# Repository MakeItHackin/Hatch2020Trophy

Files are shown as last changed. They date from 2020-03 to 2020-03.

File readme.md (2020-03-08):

Thanks for visiting this page to learn more about your HATCH trophy!  

View my YouTube video for a quick overview and demo:  
https://www.youtube.com/watch?v=jdO1fBBoojo

The trophy uses open source code and hardware, so please hack it to make it do what you want.  It comes loaded with some demo code to test each of the components.  

There will be updates to this page in the coming weeks, but if you have any questions or comments, please initiate a "Issue" on github, and I will answer as soon as I can.  

With the demo code loaded, the trophy will boot to the 'award' screen.  
Press buttons 'A' or 'B' to scroll through the menu.  
'A' and 'B' buttons serve as scrolling features through the submenus as well.  
The 'C' button is used as a 'select' button  
The 'D' button is used as a 'select' button during the 'Set Clock' Function  

When you go into the 'Demo Mode' Function, the program will loop forever.  To exit the loop, just press the reset button.  
  
The following functions are loaded with the demo software:  
View Clock (see the date/time/temperature from the DS3231 Real Time Clock module)  
Set Clock (change the clock's time)  
View Temp (see the temperature from the DS3231 Real Time Clock Module)  
Lite Sense (view the analog signal from the light sensor.  Minimum is 0 / dark and Maximum is 1023 / very very bright)  
Neopixels (cycles through a red/green/blue 'color wipe' animation)  
Buzzer (plays the Super Mario theme song)  
LEDs (cycles through LEDs on the DNA strand)  
Battery (view battery voltage)  
Demo Mode (scrolls through all features, sensors, and animations)  
  
The trophies feature the following major components:  
Arduino Nano (clone) microcontroller  
DS3231 Real Time Clock (with temperature Sensor)  
18650 Battery, along with charging circuit and DC-DC boost coverter to power the Arduino  
128x32 Pixel OLED display  
Piezo Buzzer  
Light Sensor  
Neopixel (WS2812v3) RGB LEDs  
Surface mount LEDs  
SAO v1.69 Connector

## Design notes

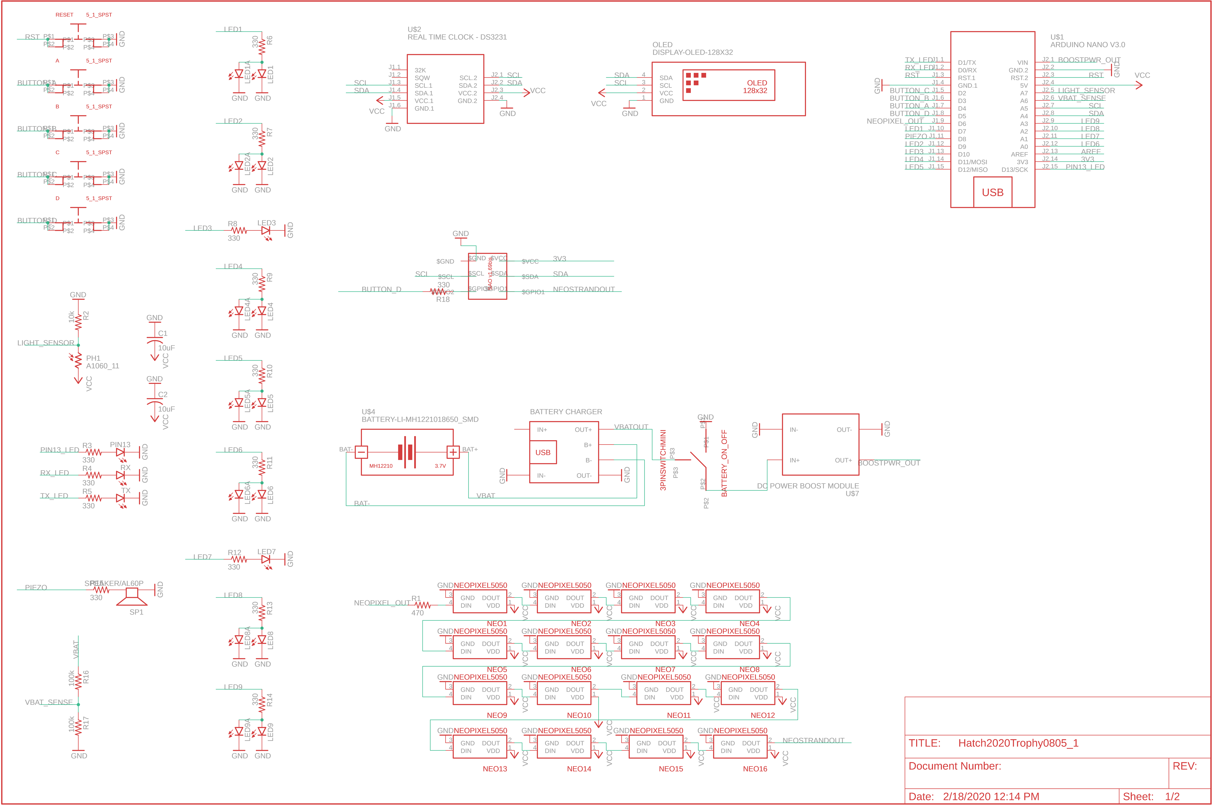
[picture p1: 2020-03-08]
CircuitBoard/TrophySchematic.png

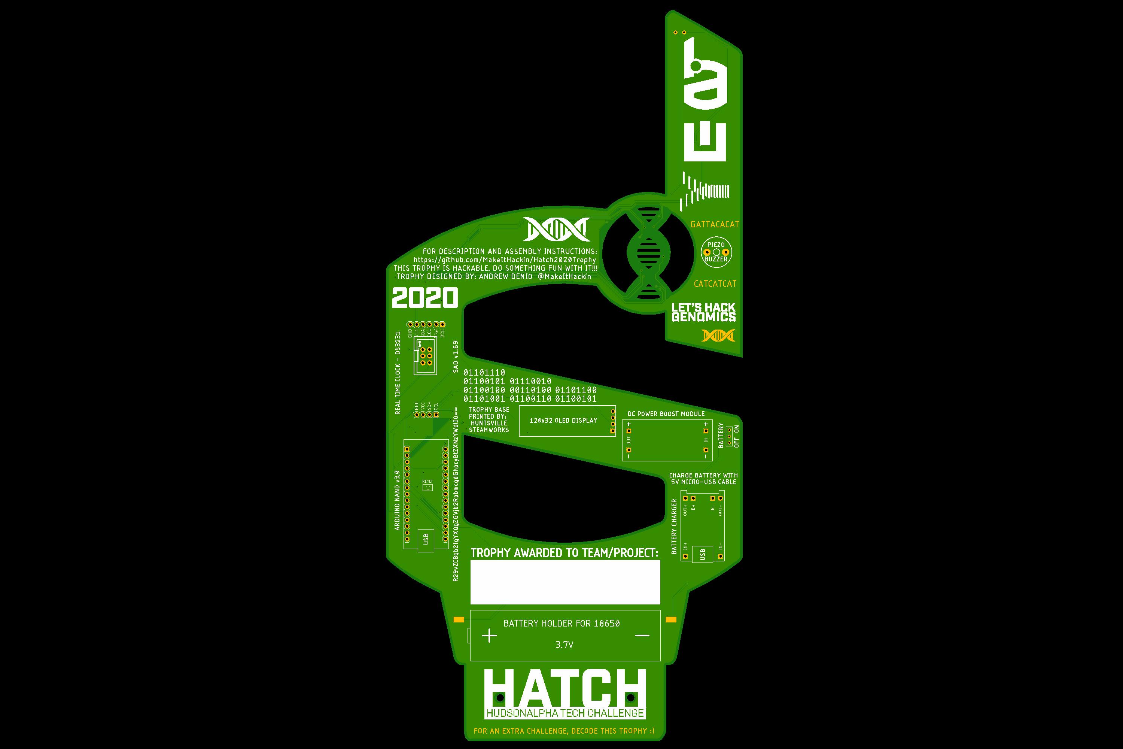
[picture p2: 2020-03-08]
CircuitBoard/TrophyBottom.jpg

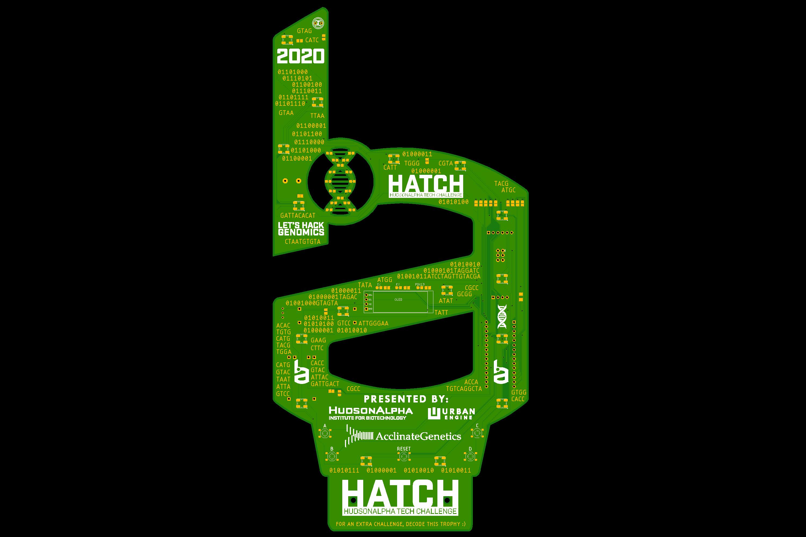
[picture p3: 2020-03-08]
CircuitBoard/TrophyTop.jpg

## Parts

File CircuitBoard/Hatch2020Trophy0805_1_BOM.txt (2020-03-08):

Partlist exported from C:/Users/Andrew/Documents/EAGLE/projects/HATCH 2020 Trophy/Hatch2020Trophy0805_1.sch at 2/18/2020 12:30 PM

Part           Value                       Device                        Package              Description                                                                                                       POPULARITY SPICEPREFIX
A              5_1_SPST                    5_1_SPST                      5_1_SPST                                                                                                                                                     
B              5_1_SPST                    5_1_SPST                      5_1_SPST                                                                                                                                                     
BATTERY_ON_OFF 3PINSWITCHMINI              3PINSWITCHMINI                3PINMINI                                                                                                                                                     
C              5_1_SPST                    5_1_SPST                      5_1_SPST                                                                                                                                                     
C1             10uF                        C-USC0805                     C0805                CAPACITOR, American symbol                                                                                        63         C          
C2             10uF                        C-USC0805                     C0805                CAPACITOR, American symbol                                                                                        63         C          
D              5_1_SPST                    5_1_SPST                      5_1_SPST                                                                                                                                                     
LED1                                       LEDSML0805                    SML0805              LED                                                                                                               17                    
LED1A                                      LEDSML0805                    SML0805              LED                                                                                                               17                    
LED2                                       LEDSML0805                    SML0805              LED                                                                                                               17                    
LED2A                                      LEDSML0805                    SML0805              LED                                                                                                               17                    
LED3                                       LEDSML0805                    SML0805              LED                                                                                                               17                    
LED4                                       LEDSML0805                    SML0805              LED                                                                                                               17                    
LED4A                                      LEDSML0805                    SML0805              LED                                                                                                               17                    
LED5                                       LEDSML0805                    SML0805              LED                                                                                                               17                    
LED5A                                      LEDSML0805                    SML0805              LED                                                                                                               17                    
LED6                                       LEDSML0805                    SML0805              LED                                                                                                               17                    
LED6A                                      LEDSML0805                    SML0805              LED                                                                                                               17                    
LED7                                       LEDSML0805                    SML0805              LED                                                                                                               17                    
LED8                                       LEDSML0805                    SML0805              LED                                                                                                               17                    
LED8A                                      LEDSML0805                    SML0805              LED                                                                                                               17                    
LED9                                       LEDSML0805                    SML0805              LED                                                                                                               17                    
LED9A                                      LEDSML0805                    SML0805              LED                                                                                                               17                    
NEO1           NEOPIXEL5050                NEOPIXEL5050                  NEOPIXEL5050                                                                                                                                                 
NEO2           NEOPIXEL5050                NEOPIXEL5050                  NEOPIXEL5050                                                                                                                                                 
NEO3           NEOPIXEL5050                NEOPIXEL5050                  NEOPIXEL5050                                                                                                                                                 
NEO4           NEOPIXEL5050                NEOPIXEL5050                  NEOPIXEL5050                                                                                                                                                 
NEO5           NEOPIXEL5050                NEOPIXEL5050                  NEOPIXEL5050                                                                                                                                                 
NEO6           NEOPIXEL5050                NEOPIXEL5050                  NEOPIXEL5050                                                                                                                                                 
NEO7           NEOPIXEL5050                NEOPIXEL5050                  NEOPIXEL5050                                                                                                                                                 
NEO8           NEOPIXEL5050                NEOPIXEL5050                  NEOPIXEL5050                                                                                                                                                 
NEO9           NEOPIXEL5050                NEOPIXEL5050                  NEOPIXEL5050                                                                                                                                                 
NEO10          NEOPIXEL5050                NEOPIXEL5050                  NEOPIXEL5050                                                                                                                                                 
NEO11          NEOPIXEL5050                NEOPIXEL5050                  NEOPIXEL5050                                                                                                                                                 
NEO12          NEOPIXEL5050                NEOPIXEL5050                  NEOPIXEL5050                                                                                                                                                 
NEO13          NEOPIXEL5050                NEOPIXEL5050                  NEOPIXEL5050                                                                                                                                                 
NEO14          NEOPIXEL5050                NEOPIXEL5050                  NEOPIXEL5050                                                                                                                                                 
NEO15          NEOPIXEL5050                NEOPIXEL5050                  NEOPIXEL5050                                                                                                                                                 
NEO16          NEOPIXEL5050                NEOPIXEL5050                  NEOPIXEL5050                                                                                                                                                 
OLED           DISPLAY-OLED-128X32         DISPLAY-OLED-128X32           DISPLAY-OLED-128X32  128x32 Dot Matrix OLED Module with I2C interface based on SSD1306 chip                                                                  
PH1            A1060_11                    A1060_11                      T0-46-A10XX          Sensor Robust Light Sensing Applications                                                                          0                     
PIN13                                      LEDSML0805                    SML0805              LED                                                                                                               17                    
R1             470                         R-US_R0805                    R0805                RESISTOR, American symbol                                                                                         85         R          
R2             10k                         R-US_R0805                    R0805                RESISTOR, American symbol                                                                                         85         R          
R3             330                         R-US_R0805                    R0805                RESISTOR, American symbol                                                                                         85         R          
R4             330                         R-US_R0805                    R0805                RESISTOR, American symbol                                                                                         85         R          
R5             330                         R-US_R0805                    R0805                RESISTOR, American symbol                                                                                         85         R          
R6             330                         R-US_R0805                    R0805                RESISTOR, American symbol                                                                                         85         R          
R7             330                         R-US_R0805                    R0805                RESISTOR, American symbol                                                                                         85         R          
R8             330                         R-US_R0805                    R0805                RESISTOR, American symbol                                                                                         85         R          
R9             330                         R-US_R0805                    R0805                RESISTOR, American symbol                                                                                         85         R          
R10            330                         R-US_R0805                    R0805                RESISTOR, American symbol                                                                                         85         R          
R11            330                         R-US_R0805                    R0805                RESISTOR, American symbol                                                                                         85         R          
R12            330                         R-US_R0805                    R0805                RESISTOR, American symbol                                                                                         85         R          
R13            330                         R-US_R0805                    R0805                RESISTOR, American symbol                                                                                         85         R          
R14            330                         R-US_R0805                    R0805                RESISTOR, American symbol                                                                                         85         R          
R15            330                         R-US_R0805                    R0805                RESISTOR, American symbol                                                                                         85         R          
R16            100k                        R-US_R0805                    R0805                RESISTOR, American symbol                                                                                         85         R          
R17            100k                        R-US_R0805                    R0805                RESISTOR, American symbol                                                                                         85         R          
R18            330                         R-US_R1206                    R1206                RESISTOR, American symbol                                                                                         19         R          
RESET          5_1_SPST                    5_1_SPST                      5_1_SPST                                                                                                                                                     
RX                                         LEDSML0805                    SML0805              LED                                                                                                               17                    
SP1            SPEAKER/AL60P               SPEAKER/AL60P                 AL60P                SPEAKER Source: BuerklinAdded PS12 (for part # PS1240 piezo) http://www.ladyada.net/library/pcb/eaglelibrary.html                       
TX                                         LEDSML0805                    SML0805              LED                                                                                                               17                    
U$1            ARDUINO NANO V3.0           ARDUINO-NANO-3.0              ARDUINO-NANO-3.0     Arduino Nano 3.0 and compatible devices                                                                                                 
U$2            REAL TIME CLOCK - DS3231    RTC-DS3231-AT24C32            RTC-DS3231-AT24C32   RTC Module with Battery and EEPROM based on DS3231 and AT24C32 chips                                                                    
U$3            SAO-1.69                    SAO-1.69                      2X3-SHROUDED-FEMALE                                                                                                                                          
U$4            BATTERY-LI-MH1221018650_SMD BATTERY-LI-MH1221018650_SMD   BATTERY_18650_SMD    Lithium-Ion MH12210 Rechargeable Battery                                                                                                
U$6            BATTERY CHARGER             BATTERY-CHARGER-LI-PROTLOW_FP BAT_CHARGE_LOW_FP    Lithium Battery 5V Charger with protection circuit                                                                                      
U$7            DC POWER BOOST MODULE       DC-DC-STEP-UP-MT3608LOW_FP    DC-DC-STEP-UP-LOW_FP DC/DC Step-Up Regulator based on MT3608 chip

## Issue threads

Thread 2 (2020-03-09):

0805 SMD LEDs too bright?

MakeItHackin, 2020-03-09:
The surface mounted LEDs in the DNA strand and above the OLED display might be a little too bright.  Changing out the resistors to a higher resistance may help (but would require resoldering).  I'll consider increasing the resistance if other trophies are ordered

Closed 2020-03-10.

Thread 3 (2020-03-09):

Some trophies will not upload code to Arduino while Arduino is plugged into trophy

MakeItHackin, 2020-03-09:
Some trophies will not upload code to Arduino while Arduino is plugged into trophy.  But upload works fine when arduino is unplugged.  I'm not sure why this is happening.

MakeItHackin, 2020-03-10:
seems to be going into some kind of reset mode.  the com port disappears for a few seconds in Device manager and Windows plays a tone like the device has disconnected.  The device reconnects, but doesn't play the "reconnecting" sound.  The LEDs on arduino also indicate that the board is going through some sort of reset.

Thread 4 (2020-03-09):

Weird Sound seems to be coming from buzzer during LED animations

MakeItHackin, 2020-03-09:
During LED animations (regular and neo pixel), some trophies produce a high pitch, very low volume noise.  I'm not sure where this is coming from or what is causing it.  I will try and troubleshoot and resolve it.

MakeItHackin, 2020-03-10:
Apparently, this has happened with other people and is said to be caused by the power circuit on the oled display.  i might try and add some pullup or pulldown resistors to see if it changes anything.

MakeItHackin, 2020-03-10:
Seems to have reduced slightly in TrophyDemoMode12 build

MakeItHackin, 2020-03-10:
Seems to have reduced slightly in TrophyDemoMode12 build

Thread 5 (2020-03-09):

Reassign the 'C' button functionality for 'select'.  Use 'D' Button instead

MakeItHackin, 2020-03-09:
'C' is assigned to the interrupt pin (2).  Save that button for something else.  Use 'D' instead to beused as select for everything else.  It is currently being used as the select button for setting the clock.

MakeItHackin, 2020-03-10:
Changed with TophyDemoMode12.

Closed 2020-03-10.

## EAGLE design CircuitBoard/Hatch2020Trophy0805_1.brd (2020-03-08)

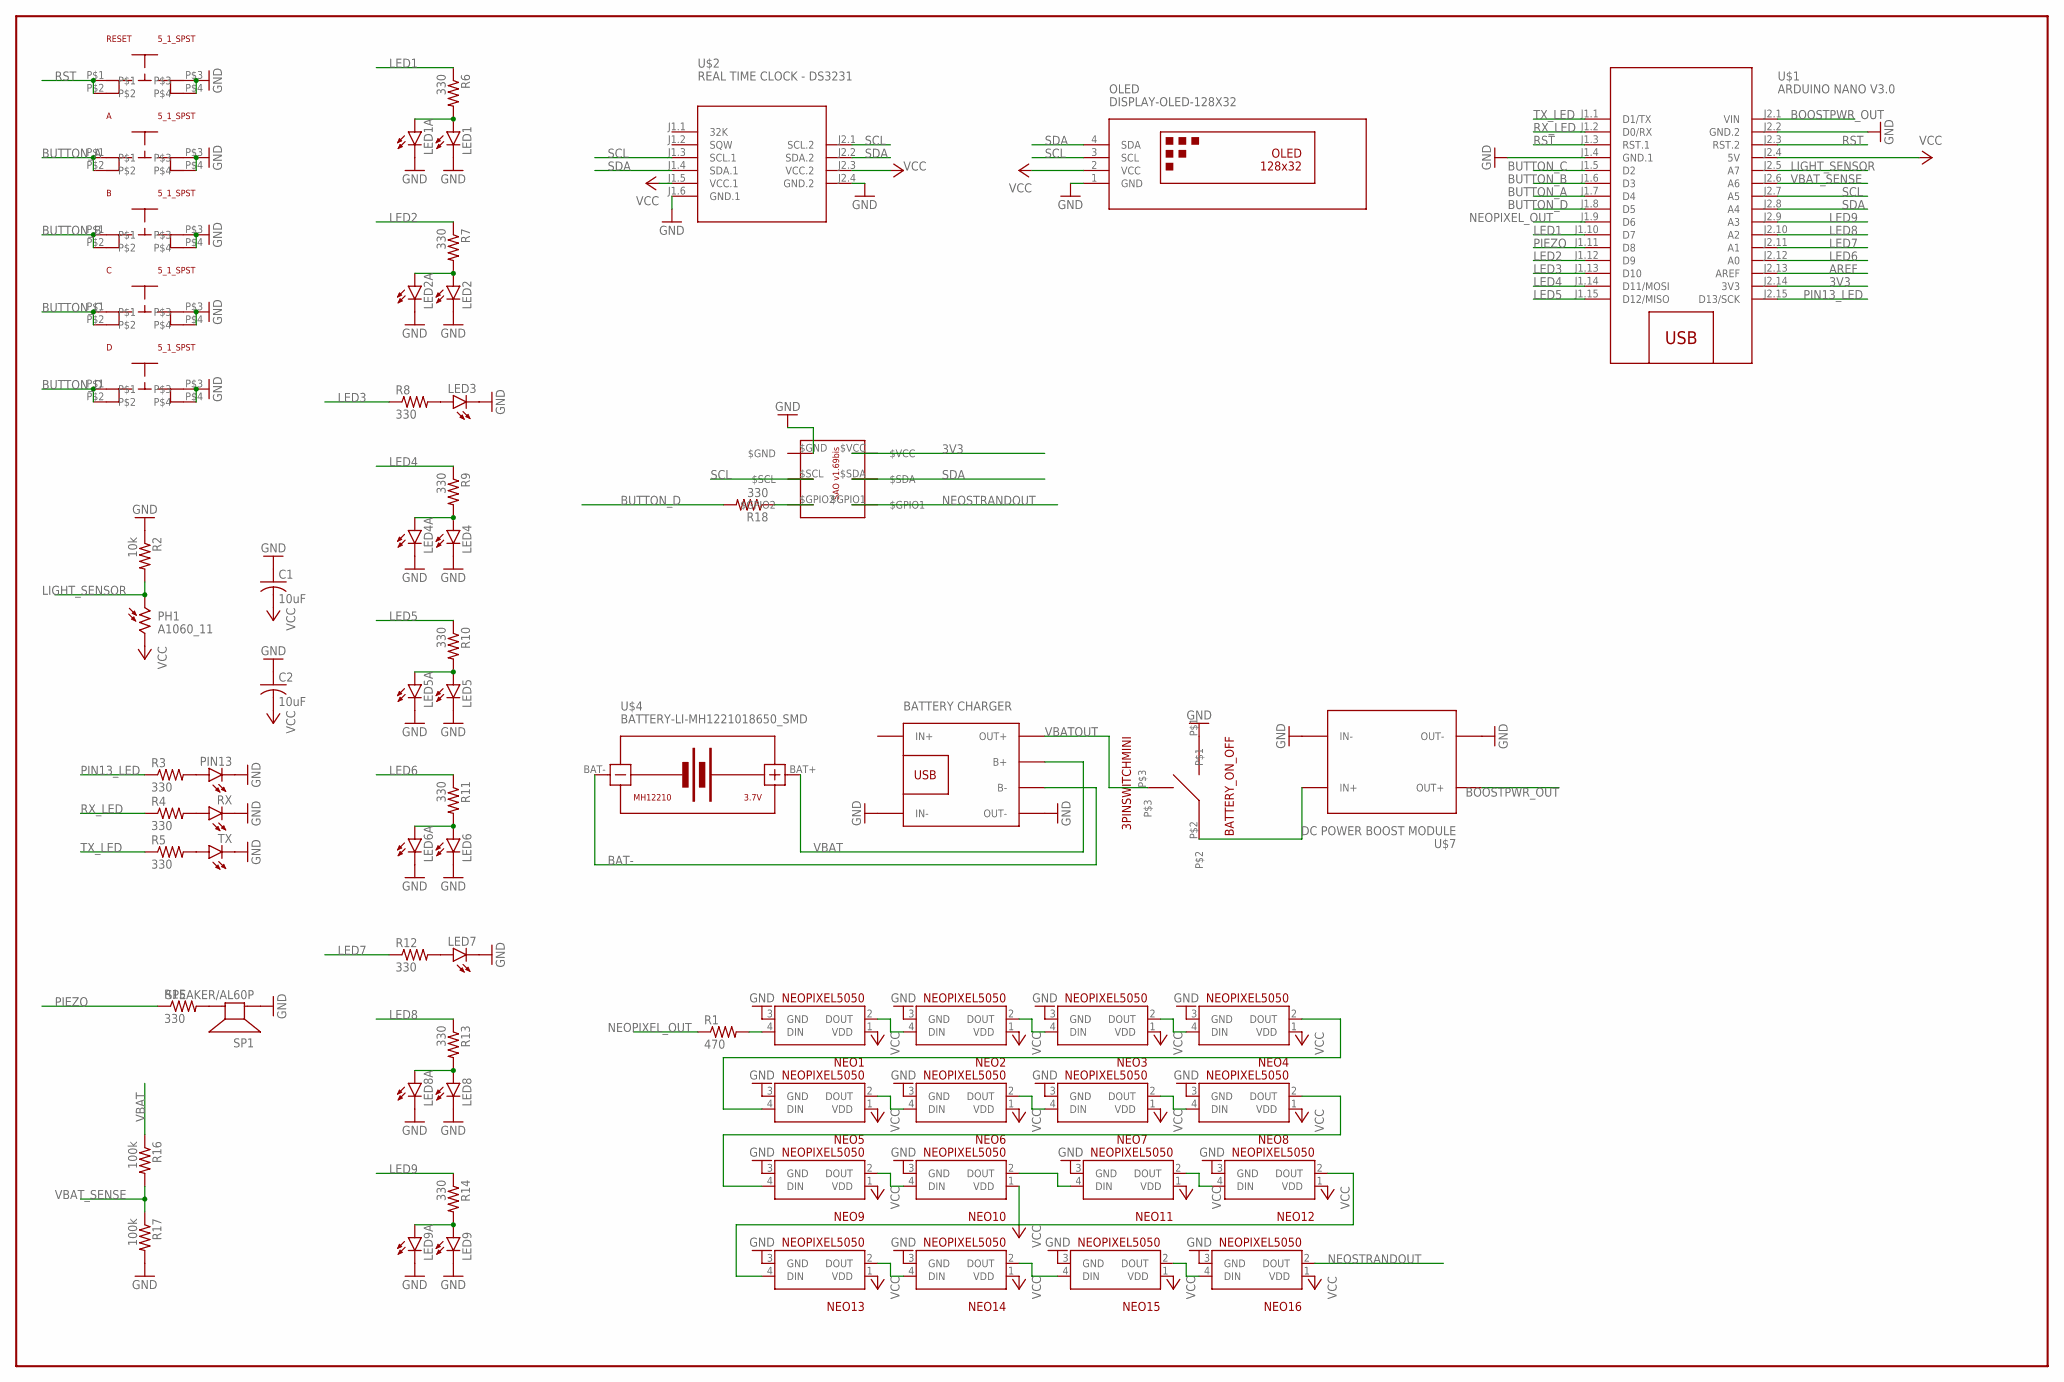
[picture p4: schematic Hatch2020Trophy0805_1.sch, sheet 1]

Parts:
A: 5_1_SPST
B: 5_1_SPST
BATTERY_ON_OFF: 3PINSWITCHMINI; 3PINMINI
C: 5_1_SPST
C1, C2: 10uF; C0805
D: 5_1_SPST
LED1, LED1A, LED2, LED2A, LED3, LED4, LED4A, LED5, LED5A, LED6, LED6A, LED7, LED8, LED8A, LED9, LED9A: LEDSML0805; SML0805
NEO1, NEO2, NEO3, NEO4, NEO5, NEO6, NEO7, NEO8, NEO9, NEO10, NEO11, NEO12, NEO13, NEO14, NEO15, NEO16: NEOPIXEL5050
OLED: DISPLAY-OLED-128X32
PH1: A1060_11; T0-46-A10XX
PIN13: LEDSML0805; SML0805
R1: 470; R0805
R2: 10k; R0805
R3, R4, R5, R6, R7, R8, R9, R10, R11, R12, R13, R14, R15: 330; R0805
R16, R17: 100k; R0805
R18: 330; R1206
RESET: 5_1_SPST
RX: LEDSML0805; SML0805
SP1: SPEAKER/AL60P; AL60P
TX: LEDSML0805; SML0805
U$1: ARDUINO NANO V3.0; ARDUINO-NANO-3.0
U$2: REAL TIME CLOCK - DS3231; RTC-DS3231-AT24C32
U$3: SAO-1.69; 2X3-SHROUDED-FEMALE
U$4: BATTERY-LI-MH1221018650_SMD; BATTERY_18650_SMD
U$6: BATTERY CHARGER; BAT_CHARGE_LOW_FP
U$7: DC POWER BOOST MODULE; DC-DC-STEP-UP-LOW_FP

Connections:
3V3: U$1.J2.14 (3V3), U$3.$VCC
AREF: U$1.J2.13 (AREF)
BAT-: U$4.BAT-, U$6.B-
BOOSTPWR_OUT: U$1.J2.1 (VIN), U$7.OUT+
BUTTON_A: A.P$1, A.P$2, U$1.J1.7 (D4)
BUTTON_B: B.P$1, B.P$2, U$1.J1.6 (D3)
BUTTON_C: C.P$1, C.P$2, U$1.J1.5 (D2)
BUTTON_D: D.P$1, D.P$2, R18.2, U$1.J1.8 (D5)
GND: A.P$3, A.P$4, B.P$3, B.P$4, BATTERY_ON_OFF.P$1, C.P$3, C.P$4, C1.1, C2.1, D.P$3, D.P$4, LED1.C, LED1A.C, LED2.C, LED2A.C, LED3.C, LED4.C, LED4A.C, LED5.C, LED5A.C, LED6.C, LED6A.C, LED7.C, LED8.C, LED8A.C, LED9.C, LED9A.C, NEO1.3 (GND), NEO2.3 (GND), NEO3.3 (GND), NEO4.3 (GND), NEO5.3 (GND), NEO6.3 (GND), NEO7.3 (GND), NEO8.3 (GND), NEO9.3 (GND), NEO10.3 (GND), NEO11.3 (GND), NEO12.3 (GND), NEO13.3 (GND), NEO14.3 (GND), NEO15.3 (GND), NEO16.3 (GND), OLED.1 (GND), PIN13.C, R2.1, R17.2, RESET.P$3, RESET.P$4, RX.C, SP1.1 (+), TX.C, U$1.J1.4 (GND.1), U$1.J2.2 (GND.2), U$2.J1.6 (GND.1), U$2.J2.4 (GND.2), U$3.$GND, U$6.IN-, U$6.OUT-, U$7.IN-, U$7.OUT-
LED1: R6.1, U$1.J1.10 (D7)
LED1W: LED1.A, LED1A.A, R6.2
LED2: R7.1, U$1.J1.12 (D9)
LED2W: LED2.A, LED2A.A, R7.2
LED3: R8.1, U$1.J1.13 (D10)
LED3W: LED3.A, R8.2
LED4: R9.1, U$1.J1.14 (D11/MOSI)
LED4W: LED4.A, LED4A.A, R9.2
LED5: R10.1, U$1.J1.15 (D12/MISO)
LED5W: LED5.A, LED5A.A, R10.2
LED6: R11.1, U$1.J2.12 (A0)
LED6W: LED6.A, LED6A.A, R11.2
LED7: R12.1, U$1.J2.11 (A1)
LED7W: LED7.A, R12.2
LED8: R13.1, U$1.J2.10 (A2)
LED8W: LED8.A, LED8A.A, R13.2
LED9: R14.1, U$1.J2.9 (A3)
LED9W: LED9.A, LED9A.A, R14.2
LIGHT_SENSOR: PH1.1, R2.2, U$1.J2.5 (A7)
unnamed: NEO13.2 (DOUT), NEO14.4 (DIN)
unnamed: NEO11.2 (DOUT), NEO12.4 (DIN)
unnamed: NEO12.2 (DOUT), NEO13.4 (DIN)
unnamed: NEO14.2 (DOUT), NEO15.4 (DIN)
unnamed: NEO15.2 (DOUT), NEO16.4 (DIN)
unnamed: R15.2, SP1.2 (-)
unnamed: R18.1, U$3.$GPIO2
unnamed: NEO4.2 (DOUT), NEO5.4 (DIN)
unnamed: NEO1.4 (DIN), R1.2
unnamed: NEO8.2 (DOUT), NEO9.4 (DIN)
unnamed: PIN13.A, R3.2
unnamed: R4.2, RX.A
unnamed: R5.2, TX.A
unnamed: NEO1.2 (DOUT), NEO2.4 (DIN)
unnamed: NEO2.2 (DOUT), NEO3.4 (DIN)
unnamed: NEO3.2 (DOUT), NEO4.4 (DIN)
unnamed: NEO5.2 (DOUT), NEO6.4 (DIN)
unnamed: NEO6.2 (DOUT), NEO7.4 (DIN)
unnamed: NEO7.2 (DOUT), NEO8.4 (DIN)
unnamed: NEO9.2 (DOUT), NEO10.4 (DIN)
unnamed: NEO10.2 (DOUT), NEO11.4 (DIN)
NEOPIXEL_OUT: R1.1, U$1.J1.9 (D6)
NEOSTRANDOUT: NEO16.2 (DOUT), U$3.$GPIO1
PIEZO: R15.1, U$1.J1.11 (D8)
PIN13_LED: R3.1, U$1.J2.15 (D13/SCK)
RST: RESET.P$1, RESET.P$2, U$1.J1.3 (RST.1), U$1.J2.3 (RST.2)
RX_LED: R4.1, U$1.J1.2 (D0/RX)
SCL: OLED.3 (SCL), U$1.J2.7 (A5), U$2.J1.3 (SCL.1), U$2.J2.1 (SCL.2), U$3.$SCL
SDA: OLED.4 (SDA), U$1.J2.8 (A4), U$2.J1.4 (SDA.1), U$2.J2.2 (SDA.2), U$3.$SDA
TX_LED: R5.1, U$1.J1.1 (D1/TX)
VBAT: R16.1, U$4.BAT+, U$6.B+
VBATOUT: BATTERY_ON_OFF.P$3, U$6.OUT+
VBAT_SENSE: R16.2, R17.1, U$1.J2.6 (A6)
VBOOST_IN: BATTERY_ON_OFF.P$2, U$7.IN+
VCC: C1.2, C2.2, NEO1.1 (VDD), NEO2.1 (VDD), NEO3.1 (VDD), NEO4.1 (VDD), NEO5.1 (VDD), NEO6.1 (VDD), NEO7.1 (VDD), NEO8.1 (VDD), NEO9.1 (VDD), NEO10.1 (VDD), NEO11.1 (VDD), NEO12.1 (VDD), NEO13.1 (VDD), NEO14.1 (VDD), NEO15.1 (VDD), NEO16.1 (VDD), OLED.2 (VCC), PH1.2, U$1.J2.4 (5V), U$2.J1.5 (VCC.1), U$2.J2.3 (VCC.2)

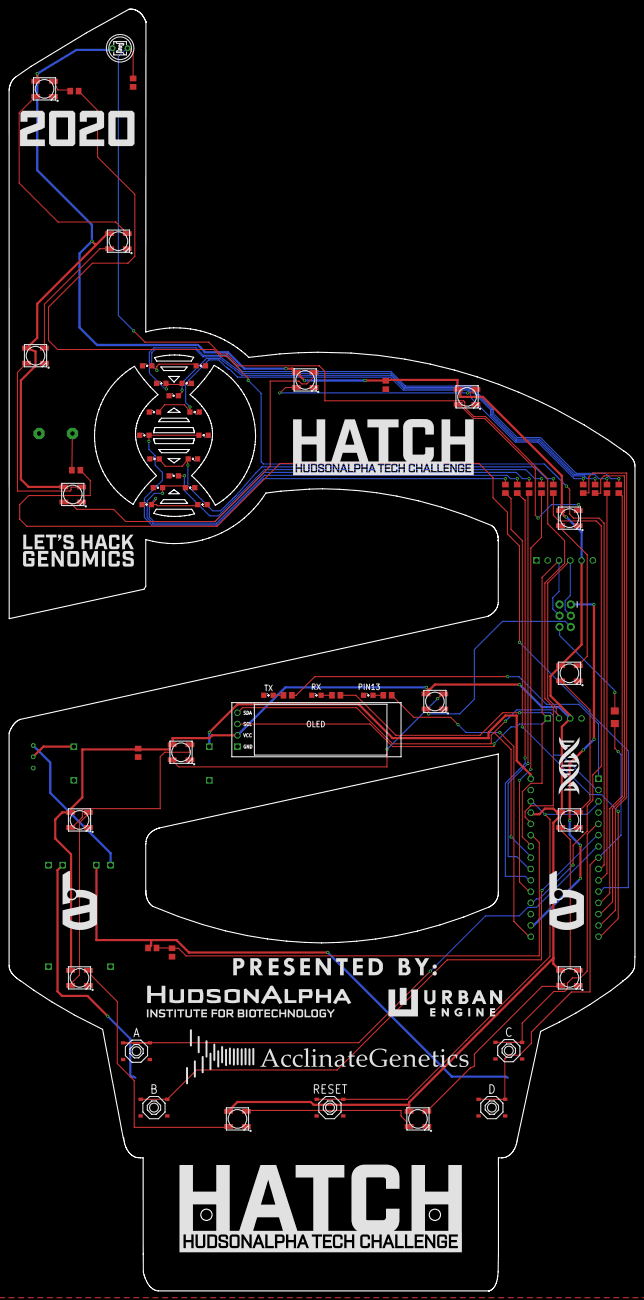
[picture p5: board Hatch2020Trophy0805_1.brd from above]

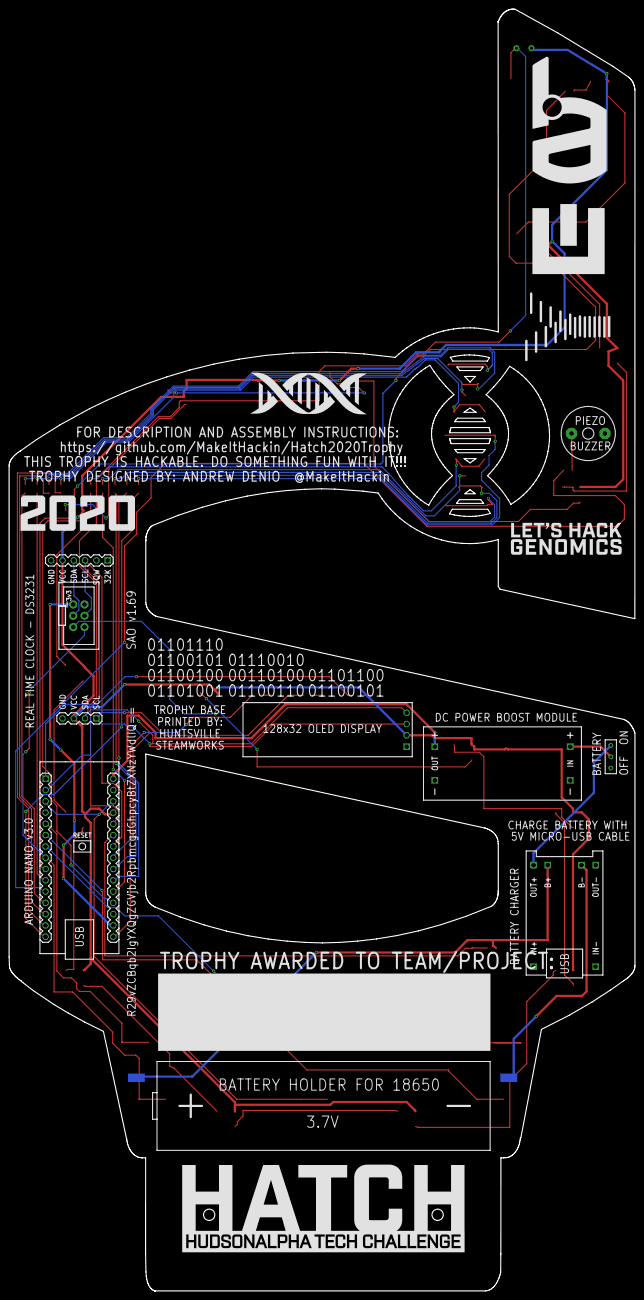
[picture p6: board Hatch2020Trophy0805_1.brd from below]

Board: 2 copper layers, 140.9 x 288.6 mm, 70 parts (7 on the bottom side), 62 nets.

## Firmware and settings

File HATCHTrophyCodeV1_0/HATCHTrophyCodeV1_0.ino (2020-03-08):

//////////////////////////////////////////////////////////////////////////////////////////////////
//////////  2020 Hudson Alpha Tech Challenge - TROPHY DEMO CODE - BY ANDREW DENIO 
//////////////////////////////////////////////////////////////////////////////////////////////////

/*
  THIS CODE WAS USED TO DEMO THE TROPHY FOR THE AWARD CEREMONY ON SUNDAY, MARCH 8, 2020.
  THERE WERE A LOT OF LESSONS LEARNED DURING THIS PROCESS.

  THE 'A' AND 'B' BUTTONS ARE PRIMARILY USED FOR SCROLLING.  
  THE 'C' BUTTON IS USED AS A SELECT BUTTON.
  THE 'D' BUTTON IS USED AS A SELECT BUTTON WHEN CHANGING THE TIME UNDER THE 'SET CLOCK' FUNCTION.
  
  IF YOU HAVE ANY QUESTIONS OR COMMENTS, FEEL FREE TO INITIATE AN ISSUE ON GITHUB.  I PLAN TO ADD ADDITIONAL COMMENTS IN THE CODE, AND MAYBE SOME MORE FEATURES!
  
  ALL LIBRARIES FOR COMPONENTS WILL BE INCLUDED IN GITHUB LINK, SO FEEL FREE TO TINKER AROUND!
  https://github.com/MakeItHackin/Hatch2020Trophy
 */


/*

HATCH 2020 TROPHY PINOUT

ARDUINO NANO CLONE


D1/TX - CONNECTED TO OFF-BOARD RESISTOR AND LED, OTHERWISE, DO NOT USE - USB COMMUNICATION
D0/RX - CONNECTED TO OFF-BOARD RESISTOR AND LED, OTHERWISE, DO NOT USE - USB COMMUNICATION
RST - RESET BUTTON
GND - CONNECTED TO GROUND PLANE
D2 - BUTTON C (save for interrupt button?)
D3 - BUTTON B
D4 - BUTTON A
D5 - BUTTON D
D6 - NEOPIXEL OUT
D7 - LED1
D8 - PIEZO BUZZER
D9 - LED2
D10 - LED3
D11/MOSI - LED4
D12/MISO - LED5

VIN - CONNECTED TO OUTPUT FROM BOOST CONVERTER
GND - CONNECTED TO GROUND PLANE
RST - RESET BUTTON
5V - CONNECTED TO 5V BUS
A7 -  LIGHT SENSOR / (cannot be used as digital pin)
A6 - battery voltage sensor/divider / (cannot be used as digital pin)
A5 - i2c (SCL)
A4 - i2c (SDA)
A3 - LED9
A2 - LED8
A1 - LED7
A0 - LED6
AREF - NOT CONNECTED
3V3 - CONNECTED TO 3V3 BUS and SAO (IS THIS NEEDED?)
D13/SCK - CONNECTED TO OFF-BOARD RESISTOR AND LED


*/


/*

AWARD TYPE:
0 - DEMO MODE
1 - HIGH SCHOOL FIRST PLACE
2 - HIGH SCHOOL SECOND PLACE
3 - PROFESSIONAL FIRST PLACE
4 - PROFESSIONAL SECOND PLACE
5 - PROFESSIONAL THIRD PLACE
6 - HUDSON ALPHA
7 - URBAN ENGINE
8 - ACCLINATE GENETICS
9 - HATCH
*/
int awardtype = 7; //CHAGE THIS VALUE TO CHANGE THE AWARD TYPE


// Music Notes for the Super Mario Bros Theme music
#define NOTE_G6  1568
#define NOTE_C7  2093
#define NOTE_E7  2637
#define NOTE_G7  3136

// Below are the Bitmaps used for the Sponsor Logos
const unsigned char AcclinateBitmap [] PROGMEM = {
0x00, 0x00, 0x00, 0x00, 0x00, 0x00, 0x00, 0x00, 0x00, 0x00, 0x00, 0x00, 0x00, 0x00, 0x00, 0x00, 
0x00, 0x00, 0x00, 0x00, 0x00, 0x00, 0x00, 0x00, 0x00, 0x00, 0x00, 0x00, 0x00, 0x00, 0x00, 0x00, 
0x00, 0x00, 0x00, 0x00, 0x00, 0x00, 0x00, 0x00, 0x00, 0x00, 0x00, 0x00, 0x00, 0x00, 0x00, 0x00, 
0x00, 0x00, 0x00, 0x00, 0x00, 0x00, 0x00, 0x00, 0x00, 0x00, 0x00, 0x00, 0x00, 0x00, 0x00, 0x00, 
0x04, 0x00, 0x00, 0x00, 0x00, 0x00, 0x00, 0x00, 0x00, 0x00, 0x00, 0x00, 0x00, 0x00, 0x00, 0x00, 
0x04, 0x00, 0x00, 0x00, 0x00, 0x00, 0x00, 0x00, 0x00, 0x00, 0x00, 0x00, 0x00, 0x00, 0x00, 0x00, 
0x04, 0x00, 0x00, 0x00, 0x00, 0x00, 0x00, 0x00, 0x00, 0x00, 0x00, 0x00, 0x00, 0x00, 0x00, 0x00, 
0x04, 0x80, 0x00, 0x00, 0x00, 0x00, 0x00, 0x00, 0x00, 0x00, 0x00, 0x00, 0x00, 0x00, 0x00, 0x00, 
0x04, 0x80, 0x00, 0x00, 0x00, 0x00, 0x00, 0x00, 0x00, 0x00, 0x00, 0x00, 0x00, 0x00, 0x00, 0x00, 
0x04, 0x90, 0x00, 0x00, 0x00, 0x00, 0x00, 0x00, 0x00, 0x00, 0x00, 0x00, 0x00, 0x00, 0x00, 0x00, 
0x04, 0x91, 0x00, 0x00, 0x00, 0x00, 0x00, 0x00, 0x00, 0x00, 0x00, 0x00, 0x00, 0x00, 0x00, 0x00, 
0x00, 0x91, 0x20, 0x00, 0x00, 0x00, 0x00, 0x00, 0x00, 0x00, 0x00, 0x00, 0x00, 0x00, 0x00, 0x00, 
0x00, 0x91, 0x22, 0x42, 0x81, 0x00, 0x01, 0x20, 0x00, 0x20, 0x07, 0xc0, 0x00, 0x01, 0x20, 0x00, 
0x00, 0x91, 0x2b, 0x5a, 0x83, 0x00, 0x01, 0x00, 0x00, 0x20, 0x18, 0x40, 0x00, 0x01, 0x00, 0x00, 
0x00, 0x15, 0x2b, 0x5a, 0x82, 0x80, 0x01, 0x20, 0x00, 0x20, 0x10, 0x00, 0x00, 0x01, 0x20, 0x00, 
0x00, 0x15, 0x2b, 0x5a, 0x80, 0x87, 0x39, 0x27, 0xcf, 0x3b, 0x90, 0x0f, 0x7c, 0x73, 0xa3, 0xbc, 
0x00, 0x25, 0x2b, 0x5a, 0x87, 0xc4, 0x21, 0x26, 0x41, 0x26, 0x50, 0xe9, 0x26, 0xc9, 0x24, 0x24, 
0x00, 0x24, 0x2b, 0x5a, 0x84, 0x48, 0x41, 0x24, 0x47, 0x27, 0xd0, 0x4f, 0x26, 0xf9, 0x24, 0x1c, 
0x02, 0x24, 0x0b, 0x5a, 0x88, 0x4c, 0x61, 0x24, 0x4b, 0x26, 0x1c, 0x48, 0x26, 0xc1, 0x24, 0x24, 
0x02, 0x24, 0x08, 0x02, 0x1c, 0x77, 0xbf, 0xf6, 0x6f, 0xb3, 0x87, 0xc7, 0x76, 0x71, 0xf7, 0xbc, 
0x12, 0x24, 0x00, 0x00, 0x00, 0x00, 0x00, 0x00, 0x00, 0x00, 0x00, 0x00, 0x00, 0x00, 0x00, 0x00, 
0x12, 0x20, 0x00, 0x00, 0x00, 0x00, 0x00, 0x00, 0x00, 0x00, 0x00, 0x00, 0x00, 0x00, 0x00, 0x00, 
0x12, 0x20, 0x00, 0x00, 0x00, 0x00, 0x00, 0x00, 0x00, 0x00, 0x00, 0x00, 0x00, 0x00, 0x00, 0x00, 
0x12, 0x00, 0x00, 0x00, 0x00, 0x00, 0x00, 0x00, 0x00, 0x00, 0x00, 0x00, 0x00, 0x00, 0x00, 0x00, 
0x10, 0x00, 0x00, 0x00, 0x00, 0x00, 0x00, 0x00, 0x00, 0x00, 0x00, 0x00, 0x00, 0x00, 0x00, 0x00, 
0x10, 0x00, 0x00, 0x00, 0x00, 0x00, 0x00, 0x00, 0x00, 0x00, 0x00, 0x00, 0x00, 0x00, 0x00, 0x00, 
0x10, 0x00, 0x00, 0x00, 0x00, 0x00, 0x00, 0x00, 0x00, 0x00, 0x00, 0x00, 0x00, 0x00, 0x00, 0x00, 
0x10, 0x00, 0x00, 0x00, 0x00, 0x00, 0x00, 0x00, 0x00, 0x00, 0x00, 0x00, 0x00, 0x00, 0x00, 0x00, 
0x00, 0x00, 0x00, 0x00, 0x00, 0x00, 0x00, 0x00, 0x00, 0x00, 0x00, 0x00, 0x00, 0x00, 0x00, 0x00, 
0x00, 0x00, 0x00, 0x00, 0x00, 0x00, 0x00, 0x00, 0x00, 0x00, 0x00, 0x00, 0x00, 0x00, 0x00, 0x00, 
0x00, 0x00, 0x00, 0x00, 0x00, 0x00, 0x00, 0x00, 0x00, 0x00, 0x00, 0x00, 0x00, 0x00, 0x00, 0x00, 
0x00, 0x00, 0x00, 0x00, 0x00, 0x00, 0x00, 0x00, 0x00, 0x00, 0x00, 0x00, 0x00, 0x00, 0x00, 0x00
};


const unsigned char UrbanEngineBitmap [] PROGMEM = {
  0x00, 0x00, 0x00, 0x00, 0x00, 0x00, 0x00, 0x00, 0x00, 0x00, 0x00, 0x00, 0x00, 0x00, 0x00, 0x00, 
0x00, 0x00, 0xfe, 0x00, 0x00, 0x00, 0x00, 0x00, 0x00, 0x00, 0x00, 0x00, 0x00, 0x00, 0x00, 0x00, 
0x00, 0x00, 0xfe, 0x00, 0x00, 0x00, 0x00, 0x00, 0x00, 0x00, 0x00, 0x00, 0x00, 0x00, 0x00, 0x00, 
0x0f, 0xe0, 0xfe, 0x0f, 0xe0, 0x00, 0x00, 0x00, 0x00, 0x00, 0x00, 0x00, 0x00, 0x00, 0x00, 0x00, 
0x0f, 0xe0, 0xfe, 0x0f, 0xe0, 0x38, 0x1c, 0x07, 0xfc, 0x01, 0xfe, 0x00, 0x3e, 0x00, 0xf0, 0x38, 
0x0f, 0xe0, 0xfe, 0x0f, 0xe0, 0x38, 0x1c, 0x07, 0xfe, 0x01, 0xff, 0x00, 0x3e, 0x00, 0xf8, 0x38, 
0x0f, 0xe0, 0xfe, 0x0f, 0xe0, 0x38, 0x1c, 0x07, 0x8e, 0x01, 0xcf, 0x00, 0x3e, 0x00, 0xf8, 0x38, 
0x0f, 0xe0, 0xfe, 0x0f, 0xe0, 0x38, 0x1c, 0x07, 0x0f, 0x01, 0xc7, 0x00, 0x7f, 0x00, 0xfc, 0x38, 
0x0f, 0xe0, 0xfe, 0x0f, 0xe0, 0x38, 0x1c, 0x07, 0x0f, 0x01, 0xc7, 0x00, 0x7f, 0x00, 0xfe, 0x38, 
0x0f, 0xe0, 0xfe, 0x0f, 0xe0, 0x38, 0x1c, 0x07, 0x9e, 0x01, 0xff, 0x00, 0xf7, 0x80, 0xff, 0x38, 
0x0f, 0xe0, 0xfe, 0x0f, 0xe0, 0x38, 0x1c, 0x07, 0xfe, 0x01, 0xff, 0x00, 0xe3, 0x80, 0xef, 0x38, 
0x0f, 0xe0, 0xfe, 0x0f, 0xe0, 0x38, 0x1c, 0x07, 0xfc, 0x01, 0xff, 0x01, 0xe3, 0xc0, 0xe7, 0xf8, 
0x0f, 0xe0, 0xfe, 0x0f, 0xe0, 0x38, 0x1c, 0x07, 0xf8, 0x01, 0xc7, 0x81, 0xff, 0xc0, 0xe3, 0xf8, 
0x0f, 0xe0, 0xfe, 0x0f, 0xe0, 0x3c, 0x1c, 0x07, 0x3c, 0x01, 0xc3, 0x81, 0xff, 0xc0, 0xe1, 0xf8, 
0x0f, 0xe0, 0xfe, 0x0f, 0xe0, 0x3c, 0x3c, 0x07, 0x3c, 0x01, 0xc7, 0x83, 0xff, 0xe0, 0xe1, 0xf8, 
0x0f, 0xe0, 0xfe, 0x0f, 0xe0, 0x1f, 0xf8, 0x07, 0x1e, 0x01, 0xff, 0x83, 0x80, 0xe0, 0xe0, 0xf8, 
0x0f, 0xe0, 0xfe, 0x0f, 0xe0, 0x0f, 0xf8, 0x07, 0x0f, 0x01, 0xff, 0x07, 0x80, 0xf0, 0xe0, 0x78, 
0x0f, 0xe0, 0xfe, 0x0f, 0xe0, 0x07, 0xe0, 0x07, 0x07, 0x01, 0xfe, 0x07, 0x00, 0x70, 0xe0, 0x38, 
0x0f, 0xe0, 0xfe, 0x0f, 0xe0, 0x00, 0x00, 0x00, 0x00, 0x00, 0x00, 0x00, 0x00, 0x00, 0x00, 0x00, 
0x0f, 0xe0, 0x00, 0x0f, 0xe0, 0x00, 0x00, 0x00, 0x00, 0x00, 0x00, 0x00, 0x00, 0x00, 0x00, 0x00, 
0x0f, 0xe0, 0x00, 0x0f, 0xe0, 0x00, 0x00, 0x00, 0x00, 0x00, 0x00, 0x00, 0x00, 0x00, 0x00, 0x00, 
0x0f, 0xe0, 0x00, 0x0f, 0xe0, 0x00, 0x00, 0x00, 0x00, 0x00, 0x00, 0x00, 0x00, 0x00, 0x00, 0x00, 
0x0f, 0xe0, 0x00, 0x0f, 0xe0, 0x00, 0x7c, 0x06, 0x10, 0x03, 0x00, 0x60, 0x31, 0x80, 0xf8, 0x00, 
0x0f, 0xf0, 0x00, 0x0f, 0xe0, 0x00, 0x7c, 0x07, 0x30, 0x0f, 0xc0, 0x60, 0x31, 0x80, 0xf8, 0x00, 
0x0f, 0xff, 0xff, 0xff, 0xe0, 0x00, 0x60, 0x07, 0x30, 0x1c, 0xc0, 0x60, 0x39, 0x80, 0xc0, 0x00, 
0x0f, 0xff, 0xff, 0xff, 0xe0, 0x00, 0x7c, 0x07, 0xb0, 0x18, 0x00, 0x60, 0x3d, 0x80, 0xf8, 0x00, 
0x0f, 0xff, 0xff, 0xff, 0xe0, 0x00, 0x7c, 0x07, 0xf0, 0x39, 0xc0, 0x60, 0x3f, 0x80, 0xf8, 0x00, 
0x0f, 0xff, 0xff, 0xff, 0xe0, 0x00, 0x60, 0x06, 0xf0, 0x39, 0xe0, 0x60, 0x37, 0x80, 0xe0, 0x00, 
0x0f, 0xff, 0xff, 0xff, 0xe0, 0x00, 0x60, 0x06, 0x70, 0x1c, 0xe0, 0x60, 0x37, 0x80, 0xc0, 0x00, 
0x0f, 0xff, 0xff, 0xff, 0xe0, 0x00, 0x7c, 0x06, 0x70, 0x0f, 0xe0, 0x60, 0x33, 0x80, 0xf8, 0x00, 
0x0f, 0xff, 0xff, 0xff, 0xe0, 0x00, 0x7c, 0x06, 0x30, 0x07, 0x80, 0x60, 0x31, 0x80, 0xf8, 0x00, 
0x00, 0x00, 0x00, 0x00, 0x00, 0x00, 0x00, 0x00, 0x00, 0x00, 0x00, 0x00, 0x00, 0x00, 0x00, 0x00
};

const unsigned char HudsonAlphaBitmap [] PROGMEM = {
 0x00, 0x00, 0x00, 0x00, 0x00, 0x00, 0x00, 0x00, 0x00, 0x00, 0x00, 0x00, 0x00, 0x00, 0x00, 0x00, 
0x00, 0x00, 0x00, 0x00, 0x00, 0x00, 0x00, 0x00, 0x00, 0x00, 0x00, 0x00, 0x00, 0x00, 0x00, 0x00, 
0x00, 0x00, 0x00, 0x00, 0x00, 0x00, 0x00, 0x00, 0x00, 0x00, 0x00, 0x00, 0x00, 0x00, 0x00, 0x00, 
0x00, 0x00, 0x00, 0x00, 0x00, 0x00, 0x00, 0x00, 0x00, 0x00, 0x00, 0x00, 0x00, 0x00, 0x00, 0x00, 
0x00, 0x00, 0x00, 0x00, 0x00, 0x00, 0x00, 0x00, 0x00, 0x00, 0x00, 0x00, 0x00, 0x00, 0x00, 0x00, 
0x00, 0x00, 0x00, 0x00, 0x00, 0x00, 0x00, 0x00, 0x00, 0x00, 0x00, 0x00, 0x00, 0x00, 0x00, 0x00, 
0x30, 0x18, 0x00, 0x00, 0x00, 0x00, 0x00, 0x00, 0x00, 0x06, 0x00, 0x00, 0x00, 0x00, 0x00, 0x00, 
0x38, 0x18, 0x00, 0x00, 0x00, 0x00, 0x00, 0x00, 0x00, 0x0f, 0x00, 0x00, 0x00, 0x00, 0x00, 0x00, 
0x38, 0x18, 0xc1, 0x9f, 0xe0, 0xfc, 0x1f, 0x86, 0x0c, 0x0f, 0x03, 0x01, 0xfc, 0x60, 0xc0, 0xc0, 
0x38, 0x18, 0xc3, 0x9f, 0xf1, 0xfe, 0x3f, 0xc7, 0x0c, 0x1f, 0x83, 0x01, 0xfe, 0x60, 0xc1, 0xe0, 
0x3f, 0xf8, 0xc3, 0x98, 0x33, 0x80, 0x70, 0xe7, 0xcc, 0x19, 0x83, 0x01, 0x86, 0x60, 0xc1, 0xe0, 
0x3f, 0xf8, 0xc3, 0x98, 0x31, 0xf0, 0x60, 0xe7, 0xec, 0x39, 0xc3, 0x01, 0x8e, 0x7f, 0xc3, 0xf0, 
0x38, 0x18, 0xc3, 0x98, 0x30, 0xfe, 0x60, 0xe6, 0xfc, 0x7f, 0xe3, 0x01, 0xfe, 0x7f, 0xc7, 0x30, 
0x38, 0x18, 0xc3, 0x98, 0x30, 0x0e, 0x60, 0xe6, 0x7c, 0x7f, 0xe3, 0x01, 0xf8, 0x60, 0xc7, 0xf8, 
0x38, 0x18, 0xe3, 0x9c, 0x73, 0x8e, 0x70, 0xe6, 0x3c, 0xe0, 0x73, 0x01, 0x80, 0x60, 0xcf, 0xfc, 
0x38, 0x18, 0xff, 0x1f, 0xf3, 0xfc, 0x3f, 0xc6, 0x0c, 0xc0, 0x33, 0xf9, 0x80, 0x60, 0xcc, 0x0c, 
0x00, 0x00, 0x18, 0x00, 0x00, 0x70, 0x06, 0x02, 0x04, 0x00, 0x00, 0x01, 0x00, 0x00, 0x40, 0x00, 
0x00, 0x00, 0x00, 0x00, 0x00, 0x00, 0x00, 0x00, 0x00, 0x00, 0x00, 0x00, 0x00, 0x00, 0x00, 0x00, 
0x00, 0x00, 0x00, 0x00, 0x00, 0x00, 0x00, 0x00, 0x00, 0x00, 0x00, 0x00, 0x00, 0x00, 0x00, 0x00, 
0x00, 0x00, 0x00, 0x00, 0x00, 0x00, 0x00, 0x00, 0x00, 0x00, 0x00, 0x00, 0x00, 0x00, 0x00, 0x00, 
0x29, 0x3b, 0xd7, 0xc3, 0xde, 0x7b, 0x9c, 0x7a, 0x77, 0xbb, 0xd2, 0x93, 0xa1, 0xce, 0x90, 0x00, 
0x2d, 0xe1, 0x92, 0x44, 0x90, 0x66, 0xf6, 0x6a, 0xda, 0x22, 0x12, 0xd4, 0xa2, 0x50, 0xf0, 0x00, 
0x2f, 0xb9, 0x12, 0x44, 0x9e, 0x7e, 0x7e, 0x7a, 0x9a, 0x3a, 0x1e, 0xf4, 0xa2, 0x56, 0x60, 0x00, 
0x2b, 0x89, 0x12, 0x6c, 0x90, 0x46, 0xfc, 0x4a, 0xda, 0x22, 0x12, 0xb4, 0xa2, 0x52, 0x20, 0x00, 
0x29, 0xf9, 0x12, 0x38, 0x9e, 0x43, 0xb6, 0x7a, 0x72, 0x3b, 0xd2, 0x97, 0xbd, 0xce, 0x20, 0x00, 
0x00, 0x00, 0x00, 0x00, 0x00, 0x00, 0x00, 0x00, 0x00, 0x00, 0x00, 0x00, 0x00, 0x00, 0x00, 0x00, 
0x00, 0x00, 0x00, 0x00, 0x00, 0x00, 0x00, 0x00, 0x00, 0x00, 0x00, 0x00, 0x00, 0x00, 0x00, 0x00, 
0x00, 0x00, 0x00, 0x00, 0x00, 0x00, 0x00, 0x00, 0x00, 0x00, 0x00, 0x00, 0x00, 0x00, 0x00, 0x00, 
0x00, 0x00, 0x00, 0x00, 0x00, 0x00, 0x00, 0x00, 0x00, 0x00, 0x00, 0x00, 0x00, 0x00, 0x00, 0x00, 
0x00, 0x00, 0x00, 0x00, 0x00, 0x00, 0x00, 0x00, 0x00, 0x00, 0x00, 0x00, 0x00, 0x00, 0x00, 0x00, 
0x00, 0x00, 0x00, 0x00, 0x00, 0x00, 0x00, 0x00, 0x00, 0x00, 0x00, 0x00, 0x00, 0x00, 0x00, 0x00, 
0x00, 0x00, 0x00, 0x00, 0x00, 0x00, 0x00, 0x00, 0x00, 0x00, 0x00, 0x00, 0x00, 0x00, 0x00, 0x00
};
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
void loop () {

  // Check Each button to see if they have been pressed
  CheckButtons(); 
  MenuChange();

  //Asssignment needed for menu
  OldMenuVar = NewMenuVar; 
  
}



//////////////////////////////


////////////////////////////////////////////////////////////////
//////////  OTHER FUNCTIONS
////////////////////////////////////////////////////////////////



///////////////////////////////////////////
///////////////////////////////////////////

//Check Each Button
void CheckButtons(){
  CheckbuttonA();
  CheckbuttonB();
  CheckbuttonC();
  CheckbuttonD();
}

////////////////////////////////////////////////////////////////

void CheckbuttonA(){

    // Get current button state.
  buttonANewState = digitalRead(BUTTON_A_PIN);

  // Check if state changed from high to low (button press).
  if (buttonANewState == LOW && buttonAOldState == HIGH) {
    // Short delay to debounce button.
    delay(20);
    // Check if button is still low after debounce.
    buttonANewState = digitalRead(BUTTON_A_PIN);
    if (buttonANewState == LOW) {
      // BUTTON PRESSED
     Serial.println("BUTTON A PRESSED");
     
      ////if (oledMainMenu == 1 || NeoPixelMenuSelected == 1 || TemperatureMenuSelected == 1 || LEDMenuSelected == 1 || DemoMenuSelected == 1){
        NewMenuVar = OldMenuVar + 1;
          if (NewMenuVar == MenuCount+1) {
              NewMenuVar = 1;
          }
         
          ////startQuadMenuCounter();
        ////}
     Serial.println("button done");
    }
    else {
      // BUTTON NOT PRESSED 
    }
  }

  // Set the last button state to the old state.
  buttonAOldState = buttonANewState;

}

////////////////////////////////////////////////////////////////

void CheckbuttonB(){

    // Get current button state.
  buttonBNewState = digitalRead(BUTTON_B_PIN);

  // Check if state changed from high to low (button press).
  if (buttonBNewState == LOW && buttonBOldState == HIGH) {
    // Short delay to debounce button.
    delay(20);
    // Check if button is still low after debounce.
    buttonBNewState = digitalRead(BUTTON_B_PIN);
    if (buttonBNewState == LOW) {
      // BUTTON PRESSED
     Serial.println("BUTTON B PRESSED");
   
     //// if (oledMainMenu == 1 || NeoPixelMenuSelected == 1 || LEDMenuSelected ==1 || TemperatureMenuSelected == 1 || DemoMenuSelected == 1){        
        NewMenuVar = OldMenuVar - 1;
          if (NewMenuVar == 0) {
              NewMenuVar = MenuCount;
          }

     ////     startQuadMenuCounter();
     ////   }
     Serial.println("button done");
    }
    else {
      // BUTTON NOT PRESSED 
    }
  }

  // Set the last button state to the old state.
  buttonBOldState = buttonBNewState;

}

////////////////////////////////////////////////////////////////

void CheckbuttonC(){

    // Get current button state.
  buttonCNewState = digitalRead(BUTTON_C_PIN);

  // Check if state changed from high to low (button press).
  if (buttonCNewState == LOW && buttonCOldState == HIGH) {
    // Short delay to debounce button.
    delay(20);
    // Check if button is still low after debounce.
    buttonCNewState = digitalRead(BUTTON_C_PIN);
    if (buttonCNewState == LOW) {
      // BUTTON PRESSED
     Serial.println("BUTTON C PRESSED");
     ////selectMenuItem();
     //oledMainMenu = 0;
     GoButtonC();
     Serial.println("button done"); 
    }
    else {
      // BUTTON NOT PRESSED 
    }
  }

  // Set the last button state to the old state.
  buttonCOldState = buttonCNewState;

}

////////////////////////////////////////////////////////////////
////////////////////////////////////////////////////////////////

void GoButtonC(){
        if (NewMenuVar == 1) {
            if (OnOffBool1 == 0) {
                OnOffBool2 = 0; OnOffBool1 = 1; OnOffBool3 = 0; OnOffBool4 = 0; OnOffBool5 = 0; OnOffBool6 = 0; OnOffBool7 = 0; OnOffBool8 = 0; OnOffBool9 = 0; OnOffBool10 = 0;
              }
            else  {
                OnOffBool1 = 0;
              }   
          }
        else if (NewMenuVar == 2) {
            if (OnOffBool2 == 0) {
                OnOffBool2 = 1; OnOffBool1 = 0; OnOffBool3 = 0; OnOffBool4 = 0; OnOffBool5 = 0; OnOffBool6 = 0; OnOffBool7 = 0; OnOffBool8 = 0; OnOffBool9 = 0; OnOffBool10 = 0;
              }
            else {
                OnOffBool2 = 0;
              }   
          } 
        else if (NewMenuVar == 3)
          {
            if (OnOffBool3 == 0) {
                OnOffBool2 = 0; OnOffBool1 = 0; OnOffBool3 = 1; OnOffBool4 = 0; OnOffBool5 = 0; OnOffBool6 = 0; OnOffBool7 = 0; OnOffBool8 = 0; OnOffBool9 = 0; OnOffBool10 = 0;
              }
            else 
              {
                OnOffBool3 = 0;
              }   
          } 
        else if (NewMenuVar == 4) {
            if (OnOffBool4 == 0) {
                OnOffBool2 = 0; OnOffBool1 = 0; OnOffBool3 = 0; OnOffBool4 = 1; OnOffBool5 = 0; OnOffBool6 = 0; OnOffBool7 = 0; OnOffBool8 = 0; OnOffBool9 = 0; OnOffBool10 = 0;
              }
            else {
                OnOffBool4 = 0;
              }   
          } 
        else if (NewMenuVar == 5) {
            if (OnOffBool5 == 0) {
                OnOffBool2 = 0; OnOffBool1 = 0; OnOffBool3 = 0; OnOffBool4 = 0; OnOffBool5 = 1; OnOffBool6 = 0; OnOffBool7 = 0; OnOffBool8 = 0; OnOffBool9 = 0; OnOffBool10 = 0;
              }
            else {
                OnOffBool5 = 0;
              }   
          } 
        else if (NewMenuVar == 6) {
            if (OnOffBool6 == 0) {
                OnOffBool2 = 0; OnOffBool1 = 0; OnOffBool3 = 0; OnOffBool4 = 0; OnOffBool5 = 0; OnOffBool6 = 1; OnOffBool7 = 0; OnOffBool8 = 0; OnOffBool9 = 0; OnOffBool10 = 0;
              }
            else {
                OnOffBool6 = 0;
              }   
          }
        else if (NewMenuVar == 7) {
            if (OnOffBool7 == 0) {
                OnOffBool2 = 0; OnOffBool1 = 0; OnOffBool3 = 0; OnOffBool4 = 0; OnOffBool5 = 0; OnOffBool6 = 0; OnOffBool7 = 1; OnOffBool8 = 0; OnOffBool9 = 0; OnOffBool10 = 0;
              }
            else {
                OnOffBool7 = 0;
              }   
          }        
        else if (NewMenuVar == 8) {
            if (OnOffBool8 == 0) {
                OnOffBool2 = 0; OnOffBool1 = 0; OnOffBool3 = 0; OnOffBool4 = 0; OnOffBool5 = 0; OnOffBool6 = 0; OnOffBool7 = 0; OnOffBool8 = 1; OnOffBool9 = 0; OnOffBool10 = 0;
              }
            else {
                OnOffBool8 = 0;
              }   
          }        
        else if (NewMenuVar == 9) {
            if (OnOffBool9 == 0) {
                OnOffBool2 = 0; OnOffBool1 = 0; OnOffBool3 = 0; OnOffBool4 = 0; OnOffBool5 = 0; OnOffBool6 = 0; OnOffBool7 = 0; OnOffBool8 = 0; OnOffBool9 = 1; OnOffBool10 = 0;
              }
            else {
                OnOffBool9 = 0;
              }   
          }        
        else if (NewMenuVar == 10) {
            if (OnOffBool10 == 0) {
                OnOffBool2 = 0; OnOffBool1 = 0; OnOffBool3 = 0; OnOffBool4 = 0; OnOffBool5 = 0; OnOffBool6 = 0; OnOffBool7 = 0; OnOffBool8 = 0; OnOffBool9 = 0; OnOffBool10 = 1;
              }
            else {
                OnOffBool10 = 0;
              }   
          }       
        else {
                OnOffBool2 = 0; OnOffBool1 = 0; OnOffBool3 = 0; OnOffBool4 = 0; OnOffBool5 = 0; OnOffBool6 = 0; OnOffBool7 = 0; OnOffBool8 = 0; OnOffBool9 = 0; OnOffBool10 = 0;
              }
}

////////////////////////////////////////////////////////////////
////////////////////////////////////////////////////////////////


void CheckbuttonD(){

    // Get current button state.
  buttonDNewState = digitalRead(BUTTON_D_PIN);

  // Check if state changed from high to low (button press).
  if (buttonDNewState == LOW && buttonDOldState == HIGH) {
    // Short delay to debounce button.
    delay(20);
    // Check if button is still low after debounce.
    buttonDNewState = digitalRead(BUTTON_D_PIN);
    if (buttonDNewState == LOW) {
      // BUTTON PRESSED
     Serial.println("BUTTON D PRESSED");
    oledMainMenu = 1;
    //changeEPDToMainMenu();
    ////printEPDMenu("MAIN", "NEOPIXELS", "LIGHT SENSOR", "TEMPERATURE SENSOR", "ACCELEROMETER", "DEMO MODE", " ", 1);
    ////startQuadMenuCounter();
    Serial.println("button done");
    }
    else {
      // BUTTON NOT PRESSED 
    }
  }

  // Set the last button state to the old state.
  buttonDOldState = buttonDNewState;

}

////////////////////////////////////////////////////////////////
////////////////////////////////////////////////////////////////
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

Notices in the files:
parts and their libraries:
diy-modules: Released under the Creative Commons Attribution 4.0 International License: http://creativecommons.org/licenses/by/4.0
